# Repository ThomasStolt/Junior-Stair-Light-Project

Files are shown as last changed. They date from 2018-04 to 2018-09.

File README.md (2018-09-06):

# Junior-Stair-Light-Project

This is a smaller/easier/cheaper version of my NeoPixel Stair Light Project. The basic idea is to use a bunch of cheap 12V LEDs stripes attached to your indoor stairs, two IR sensors and an Arduino Nano and animate those LED stripes if a person is walking up or down the stairs.

I created this for a friend of mine. He went out on the internet and bought sets of LED stripes (originally thought for cars, 12V) and mounted them under the stairs. I then went ahead and created this little project around it, giving it some more fun.

For several reasons, all grounds of the LED stripes were connected together and all the positive leads were routed to the circuit for switching/PWM. Because of that, I had to use that dual-transistor circuit, which I found on the internet, to be able to switch the positive lines.
It is actually easier to switch the negative lines, that just requires one transistor/MOSFET, so if you do this and you have a choice, you should probably go with that approach.

Nothing more to add really, just read the circuit under schematics/kicad (there is a PDF) and you should be good.

# Needed Materials:

- Power supply, 12V DC, 2A should be enough (I found a 3A in my mess)
- 1 x Arduino Nano
- 2 x 10k resistors (optional, pull up for PIR sensors, I did not need to use them)
- 1 x 5V regulator (L4940V5)
- 2 x 100uF electrolytic capacitor
- 1 x 100nF ceramic capacitor
- a project box to house the electronics

Then _per step_ you need:
- 1 x LED stripe (12V, for cars)
- 2 x 1kOhm resistor
- 1 x 10kOhm resistor
- 1 x BC337 (or similar) NPN Transistor
- 1 x BC327 (or similar) PNP Transistor

Additionally you need a prototype board (or the PCB, see below) for soldering components, some wires for connecting the components, tools (soldering iron, solder, cutter, clippers, a Dremel helps to cut the copper on the board) and some time and patience.

# Printed Circuit Board
I have created a first "Release Candidate" (RC) of a printed circuit board for this project. I added the maximum number of channels (steps) that an Arduino Nano can have, which is number of Digital outputs + number of Analog outputs - 2 analog outputs (for the IR sensors), which should end up at 18.

So, 18 is the maximum number of steps your stairs can have using this single Arduino Nano module. If you have less stairs, just populate the board with the appropriate number of parts for the channels. If you have more stairs - well, you are on your own.

To order the PCB you'll need to send/upload the Gerber files to a PCB manufacturer of your choice. You can find the Gerber files here: [Gerbes](schematics/kicad/GERBERS), just use the ZIP archive. The board is 9cm x 9cm, currently you get special offers for 2$ for 10 pieces - ridicolous!

As of today (Sep 2018), I have not yet ordered a PCB, so I cannot say whether this PCB is really working, it might still be full of bugs! Try at your own risk!

# Steps:
1. buy all the material
2. create the board (see pictures), start with one channel first
3. test that first channel
4. create all the channels
5. stick it to your stairs

# Pictures

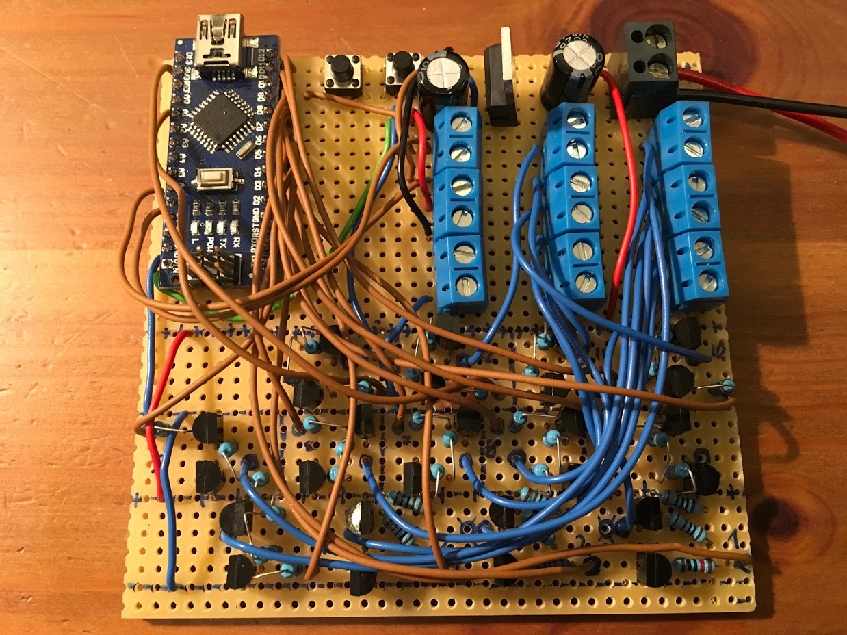
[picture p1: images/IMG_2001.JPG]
finished board top

This is the finished board, top view.

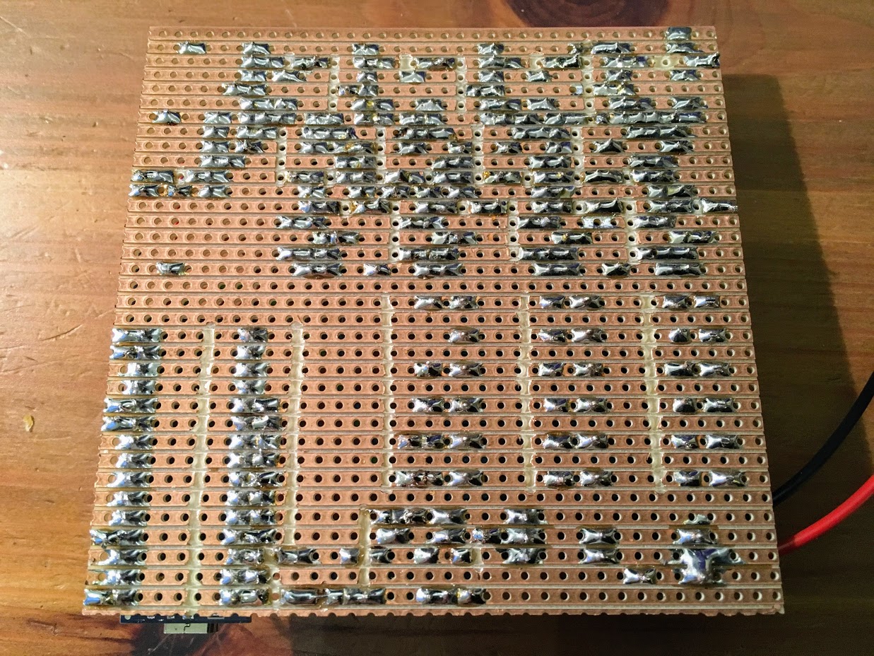
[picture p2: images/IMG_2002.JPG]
finished board bottom

This is the finished board on a prototype PCB, bottom view.

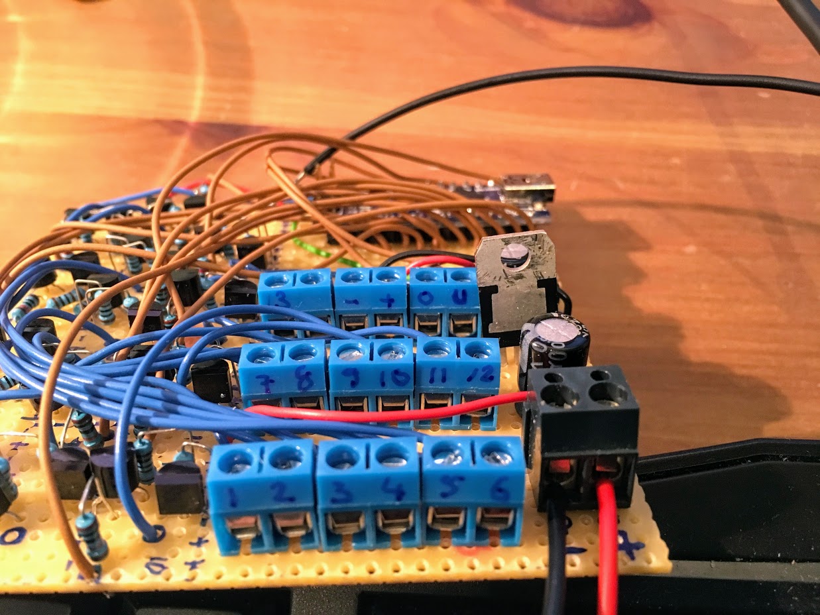
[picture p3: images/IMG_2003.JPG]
connectors view

These are the connectors for the LED strips, power and IR sensors

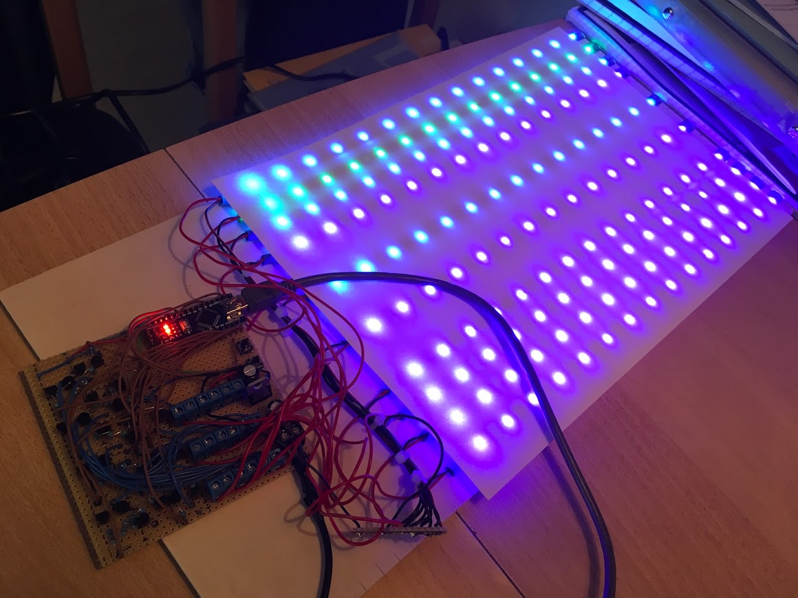
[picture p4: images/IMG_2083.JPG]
test setup

The test setup for finishing the code.
I did not have enough left over stripes, hence there are some missing here, but that is sufficient.

This can probably be done on one weekend if you are somewhat experienced.

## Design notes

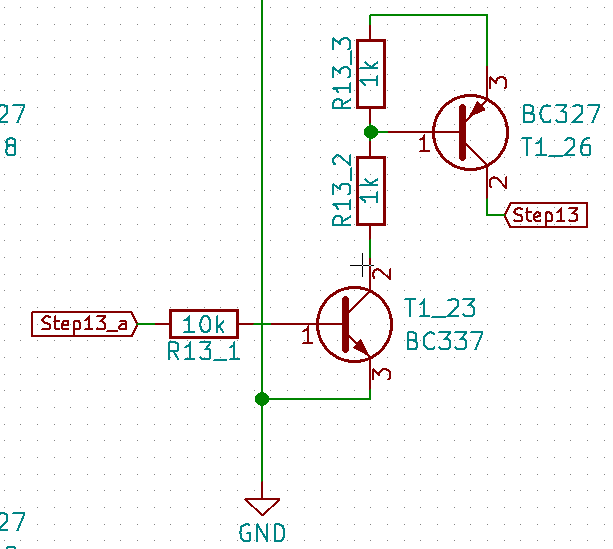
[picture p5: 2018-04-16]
images/Bildschirmfoto vom 2018-04-16 23-10-50.png

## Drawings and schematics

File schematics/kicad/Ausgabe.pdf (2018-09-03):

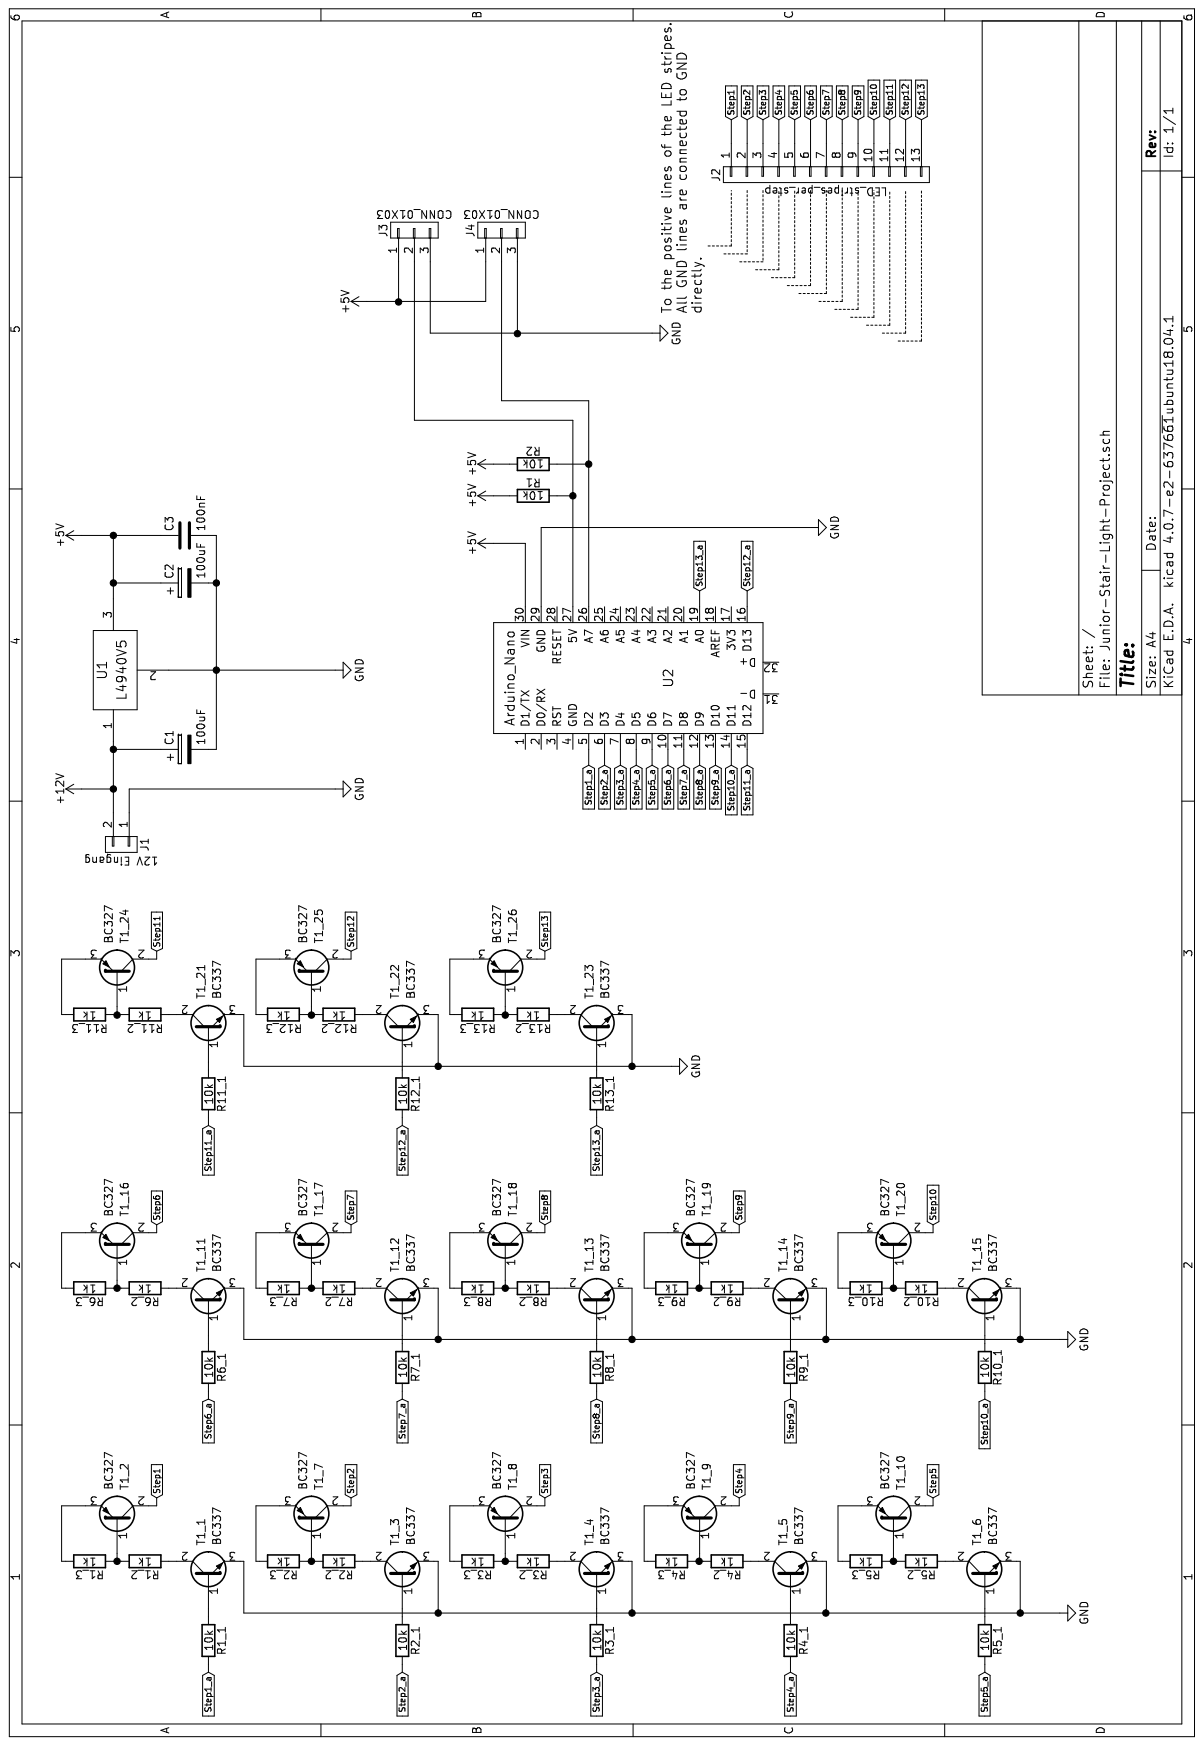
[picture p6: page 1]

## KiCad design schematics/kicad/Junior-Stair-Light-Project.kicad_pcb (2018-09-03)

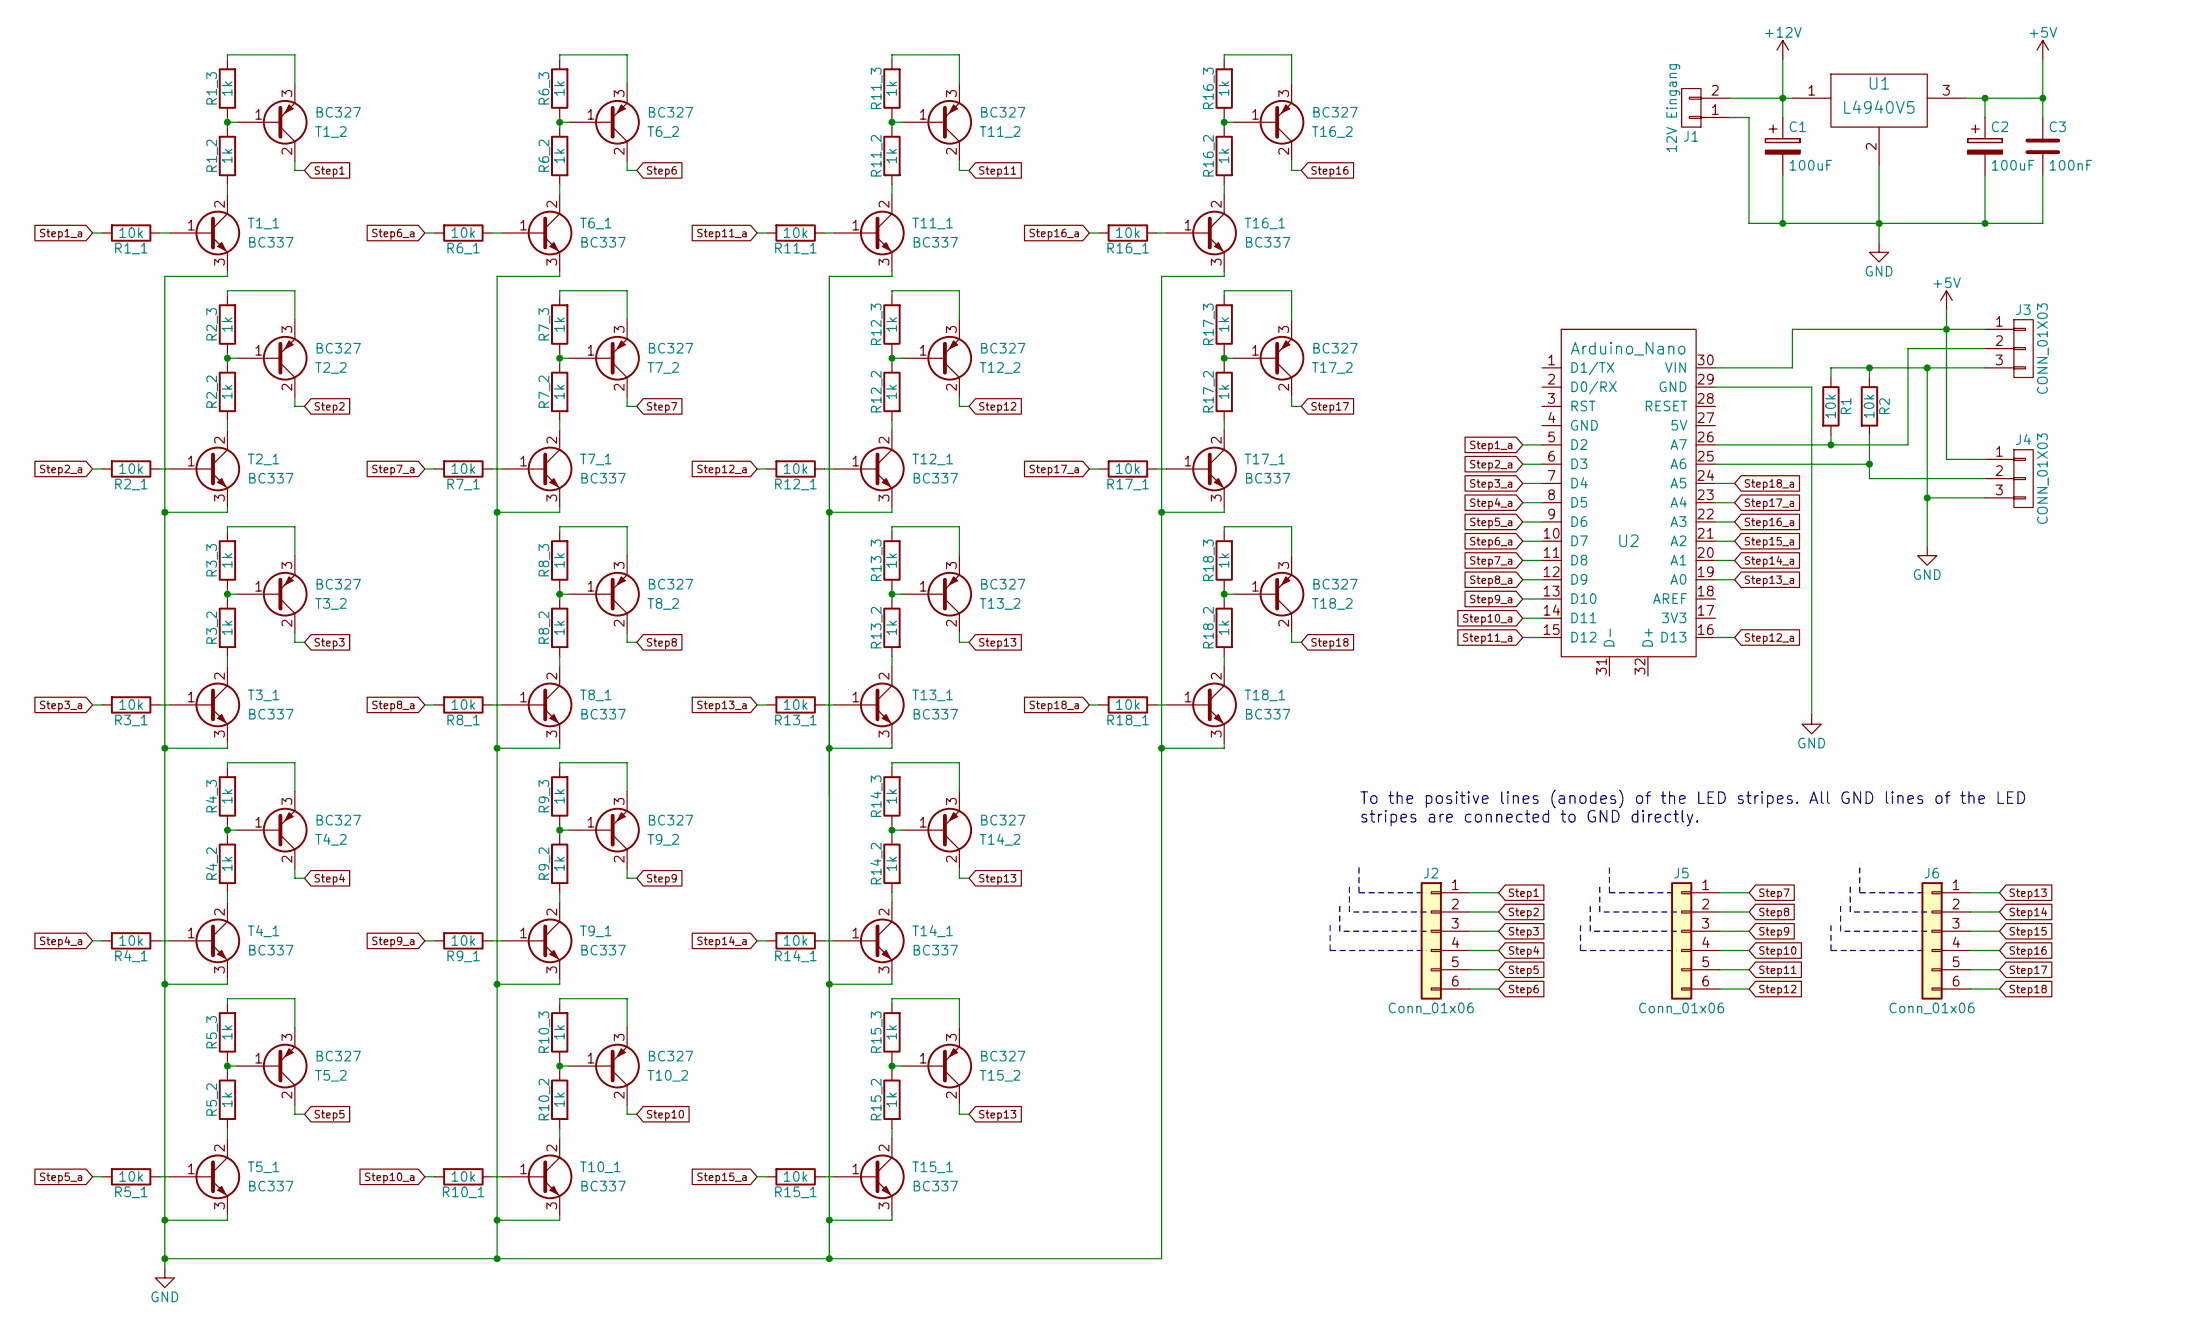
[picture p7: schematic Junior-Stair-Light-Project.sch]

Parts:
C1, C2: 100uF; CP_Radial_D7.5mm_P2.50mm
C3: 100nF; C_Disc_D3.8mm_W2.6mm_P2.50mm
J1: 12V Eingang; JST_XH_B02B-XH-A_02x2.50mm_Straight
J2, J5, J6: Conn_01x06; JST_XH_B06B-XH-A_06x2.50mm_Straight
J3, J4: CONN_01X03; JST_XH_B03B-XH-A_03x2.50mm_Straight
R1, R1_1, R2, R2_1, R3_1, R4_1, R5_1, R6_1, R7_1, R8_1, R9_1, R10_1, R11_1, R12_1, R13_1, R14_1, R15_1, R16_1, R17_1, R18_1: 10k; R_Axial_DIN0207_L6.3mm_D2.5mm_P7.62mm_Horizontal
R1_2, R1_3, R2_2, R2_3, R3_2, R3_3, R4_2, R4_3, R5_2, R5_3, R6_2, R6_3, R7_2, R7_3, R8_2, R8_3, R9_2, R9_3, R10_2, R10_3, R11_2, R11_3, R12_2, R12_3, R13_2, R13_3, R14_2, R14_3, R15_2, R15_3, R16_2, R16_3, R17_2, R17_3, R18_2, R18_3: 1k; R_Axial_DIN0207_L6.3mm_D2.5mm_P7.62mm_Horizontal
T1_1, T2_1, T3_1, T4_1, T5_1, T6_1, T7_1, T8_1, T9_1, T10_1, T11_1, T12_1, T13_1, T14_1, T15_1, T16_1, T17_1, T18_1: BC337; TO-92_Inline_Narrow_Oval
T1_2, T2_2, T3_2, T4_2, T5_2, T6_2, T7_2, T8_2, T9_2, T10_2, T11_2, T12_2, T13_2, T14_2, T15_2, T16_2, T17_2, T18_2: BC327; TO-92_Inline_Narrow_Oval
U1: L4940V5; TO-220_Vertical
U2: Arduino_Nano

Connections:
+5V: C2.1, C3.1, J3.1, J4.1, U1.3, U2.30 (VIN)
+12V: C1.1, J1.2, U1.1
GND: C1.2, C2.2, C3.2, J1.1, J3.3, J4.3, R1.1, R2.1, T1_1.3 (E), T2_1.3 (E), T3_1.3 (E), T4_1.3 (E), T5_1.3 (E), T6_1.3 (E), T7_1.3 (E), T8_1.3 (E), T9_1.3 (E), T10_1.3 (E), T11_1.3 (E), T12_1.3 (E), T13_1.3 (E), T14_1.3 (E), T15_1.3 (E), T16_1.3 (E), T17_1.3 (E), T18_1.3 (E), U1.2, U2.29 (GND)
unnamed: J3.2, R1.2, U2.26 (A7)
unnamed: J4.2, R2.2, U2.25 (A6)
unnamed: R1_1.1, T1_1.1 (B)
unnamed: R1_2.1, R1_3.1, T1_2.1 (B)
unnamed: R1_2.2, T1_1.2 (C)
unnamed: R1_3.2, T1_2.3 (E)
unnamed: R2_1.1, T2_1.1 (B)
unnamed: R2_2.1, R2_3.1, T2_2.1 (B)
unnamed: R2_2.2, T2_1.2 (C)
unnamed: R2_3.2, T2_2.3 (E)
unnamed: R3_1.1, T3_1.1 (B)
unnamed: R3_2.1, R3_3.1, T3_2.1 (B)
unnamed: R3_2.2, T3_1.2 (C)
unnamed: R3_3.2, T3_2.3 (E)
unnamed: R4_1.1, T4_1.1 (B)
unnamed: R4_2.1, R4_3.1, T4_2.1 (B)
unnamed: R4_2.2, T4_1.2 (C)
unnamed: R4_3.2, T4_2.3 (E)
unnamed: R5_1.1, T5_1.1 (B)
unnamed: R5_2.1, R5_3.1, T5_2.1 (B)
unnamed: R5_2.2, T5_1.2 (C)
unnamed: R5_3.2, T5_2.3 (E)
unnamed: R6_1.1, T6_1.1 (B)
unnamed: R6_2.1, R6_3.1, T6_2.1 (B)
unnamed: R6_2.2, T6_1.2 (C)
unnamed: R6_3.2, T6_2.3 (E)
unnamed: R7_1.1, T7_1.1 (B)
unnamed: R7_2.1, R7_3.1, T7_2.1 (B)
unnamed: R7_2.2, T7_1.2 (C)
unnamed: R7_3.2, T7_2.3 (E)
unnamed: R8_1.1, T8_1.1 (B)
unnamed: R8_2.1, R8_3.1, T8_2.1 (B)
unnamed: R8_2.2, T8_1.2 (C)
unnamed: R8_3.2, T8_2.3 (E)
unnamed: R9_1.1, T9_1.1 (B)
unnamed: R9_2.1, R9_3.1, T9_2.1 (B)
unnamed: R9_2.2, T9_1.2 (C)
unnamed: R9_3.2, T9_2.3 (E)
unnamed: R10_1.1, T10_1.1 (B)
unnamed: R10_2.1, R10_3.1, T10_2.1 (B)
unnamed: R10_2.2, T10_1.2 (C)
unnamed: R10_3.2, T10_2.3 (E)
unnamed: R11_1.1, T11_1.1 (B)
unnamed: R11_2.1, R11_3.1, T11_2.1 (B)
unnamed: R11_2.2, T11_1.2 (C)
unnamed: R11_3.2, T11_2.3 (E)
unnamed: R12_1.1, T12_1.1 (B)
unnamed: R12_2.1, R12_3.1, T12_2.1 (B)
unnamed: R12_2.2, T12_1.2 (C)
unnamed: R12_3.2, T12_2.3 (E)
unnamed: R13_1.1, T13_1.1 (B)
unnamed: R13_2.1, R13_3.1, T13_2.1 (B)
unnamed: R13_2.2, T13_1.2 (C)
unnamed: R13_3.2, T13_2.3 (E)
unnamed: R14_1.1, T14_1.1 (B)
unnamed: R14_2.1, R14_3.1, T14_2.1 (B)
unnamed: R14_2.2, T14_1.2 (C)
unnamed: R14_3.2, T14_2.3 (E)
unnamed: R15_1.1, T15_1.1 (B)
unnamed: R15_2.1, R15_3.1, T15_2.1 (B)
unnamed: R15_2.2, T15_1.2 (C)
unnamed: R15_3.2, T15_2.3 (E)
unnamed: R16_1.1, T16_1.1 (B)
unnamed: R16_2.1, R16_3.1, T16_2.1 (B)
unnamed: R16_2.2, T16_1.2 (C)
unnamed: R16_3.2, T16_2.3 (E)
unnamed: R17_1.1, T17_1.1 (B)
unnamed: R17_2.1, R17_3.1, T17_2.1 (B)
unnamed: R17_2.2, T17_1.2 (C)
unnamed: R17_3.2, T17_2.3 (E)
unnamed: R18_1.1, T18_1.1 (B)
unnamed: R18_2.1, R18_3.1, T18_2.1 (B)
unnamed: R18_2.2, T18_1.2 (C)
unnamed: R18_3.2, T18_2.3 (E)
Step1: J2.1, T1_2.2 (C)
Step1_a: R1_1.2, U2.5 (D2)
Step2: J2.2, T2_2.2 (C)
Step2_a: R2_1.2, U2.6 (D3)
Step3: J2.3, T3_2.2 (C)
Step3_a: R3_1.2, U2.7 (D4)
Step4: J2.4, T4_2.2 (C)
Step4_a: R4_1.2, U2.8 (D5)
Step5: J2.5, T5_2.2 (C)
Step5_a: R5_1.2, U2.9 (D6)
Step6: J2.6, T6_2.2 (C)
Step6_a: R6_1.2, U2.10 (D7)
Step7: J5.1, T7_2.2 (C)
Step7_a: R7_1.2, U2.11 (D8)
Step8: J5.2, T8_2.2 (C)
Step8_a: R8_1.2, U2.12 (D9)
Step9: J5.3, T9_2.2 (C)
Step9_a: R9_1.2, U2.13 (D10)
Step10: J5.4, T10_2.2 (C)
Step10_a: R10_1.2, U2.14 (D11)
Step11: J5.5, T11_2.2 (C)
Step11_a: R11_1.2, U2.15 (D12)
Step12: J5.6, T12_2.2 (C)
Step12_a: R12_1.2, U2.16 (D13)
Step13: J6.1, T13_2.2 (C), T14_2.2 (C), T15_2.2 (C)
Step13_a: R13_1.2, U2.19 (A0)
Step14: J6.2
Step14_a: R14_1.2, U2.20 (A1)
Step15: J6.3
Step15_a: R15_1.2, U2.21 (A2)
Step16: J6.4, T16_2.2 (C)
Step16_a: R16_1.2, U2.22 (A3)
Step17: J6.5, T17_2.2 (C)
Step17_a: R17_1.2, U2.23 (A4)
Step18: J6.6, T18_2.2 (C)
Step18_a: R18_1.2, U2.24 (A5)

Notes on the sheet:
To the positive lines (anodes) of the LED stripes. All GND lines of the LED stripes are connected to GND directly.

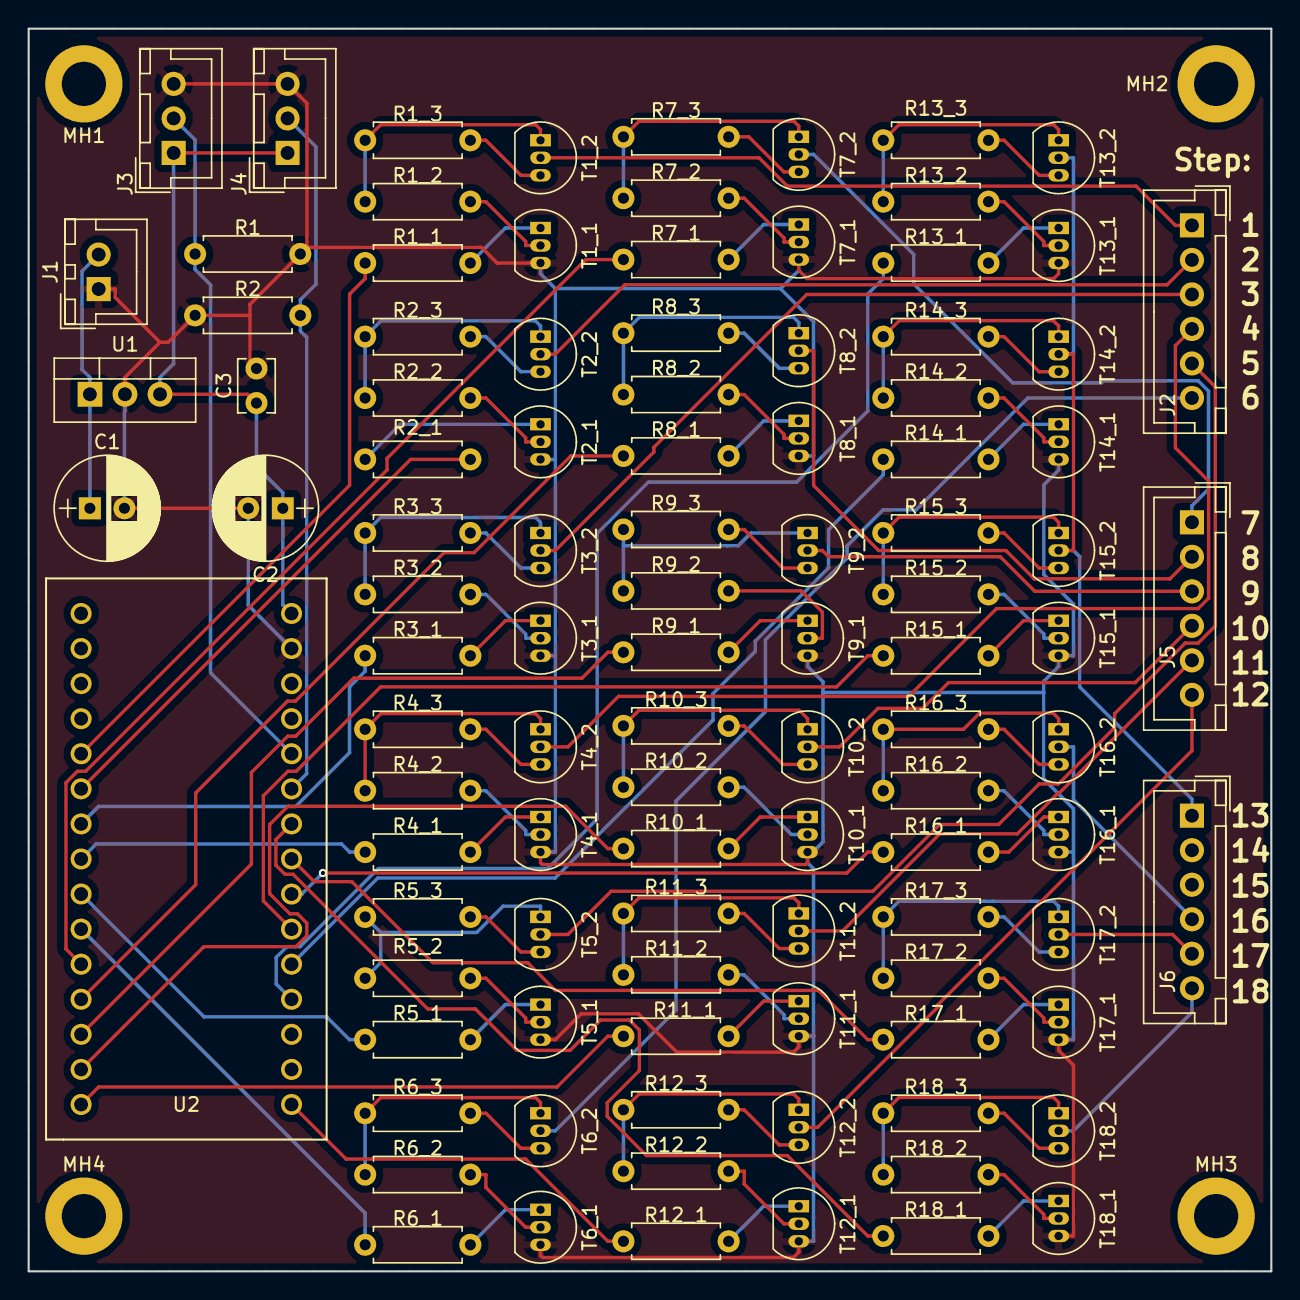
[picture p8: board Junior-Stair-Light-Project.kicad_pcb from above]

Board: 2 copper layers, 90.0 x 90.0 mm, 107 parts (0 on the bottom side), 111 nets.

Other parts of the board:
MH1: MH1; MountingHole_3.2mm_M3_DIN965_Pad
MH2: MH2; MountingHole_3.2mm_M3_DIN965_Pad
MH3: MH3; MountingHole_3.2mm_M3_DIN965_Pad
MH4: MH4; MountingHole_3.2mm_M3_DIN965_Pad

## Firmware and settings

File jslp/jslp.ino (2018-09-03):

/*
  Junior Stair Light Project
  ==========================
  This is an Arduino Nano based project. The idea is to illuminate
  a flight of stairs with some dirt cheap LED stripes, also adding
  some animation (dimming). All triggered by IR sensors.
  
  Project cost: 50€ max!
  
  I was equiping my own stairs with some RGBWW  NeoPixels, while a
  friend  of  mine  was  inspired  and  went  out  shopping on the
  internet  on a shoestring. He bought LED stripes from an obscure
  company (XINBAN). 9€ for 8 strips,  30cm  and  15LEDs each, they
  need 12V to operate.  While  crappy, I thought I could still add
  some animation and dimming functionality to it.

  I have used the Arduino-SoftPWM, which allows  you  to  use  all
  digital  AND  analog  pins for PWM. This flight of stairs has 13
  steps, but in this  configuration this project can be used up to
  18 steps.
*/

#include <SoftPWM.h>
SOFTPWM_DEFINE_CHANNEL(2, DDRD, PORTD, PORTD2);  //Arduino pin D2
SOFTPWM_DEFINE_CHANNEL(3, DDRD, PORTD, PORTD3);  //Arduino pin D3
SOFTPWM_DEFINE_CHANNEL(4, DDRD, PORTD, PORTD4);  //Arduino pin D4
SOFTPWM_DEFINE_CHANNEL(5, DDRD, PORTD, PORTD5);  //Arduino pin D5
SOFTPWM_DEFINE_CHANNEL(6, DDRD, PORTD, PORTD6);  //Arduino pin D6
SOFTPWM_DEFINE_CHANNEL(7, DDRD, PORTD, PORTD7);  //Arduino pin D7
SOFTPWM_DEFINE_CHANNEL(8, DDRB, PORTB, PORTB0);  //Arduino pin D8
SOFTPWM_DEFINE_CHANNEL(9, DDRB, PORTB, PORTB1);  //Arduino pin D9
SOFTPWM_DEFINE_CHANNEL(10, DDRB, PORTB, PORTB2);  //Arduino pin D10
SOFTPWM_DEFINE_CHANNEL(11, DDRB, PORTB, PORTB3);  //Arduino pin D11
SOFTPWM_DEFINE_CHANNEL(12, DDRB, PORTB, PORTB4);  //Arduino pin D12
SOFTPWM_DEFINE_CHANNEL(13, DDRB, PORTB, PORTB5);  //Arduino pin D13
SOFTPWM_DEFINE_CHANNEL(14, DDRC, PORTC, PORTC0);  //Arduino pin A0
SOFTPWM_DEFINE_OBJECT_WITH_PWM_LEVELS(20, 100);
SOFTPWM_DEFINE_EXTERN_OBJECT_WITH_PWM_LEVELS(20, 100);

void setup() {
  Serial.begin(19200);
  // begin with 60hz pwm frequency
  Palatis::SoftPWM.begin(60);
  // print interrupt load for diagnostic purposes
  Palatis::SoftPWM.printInterruptLoad();
}

static volatile uint8_t v = 0;
int analog_threshold = 100;
int animation_duration = 30000;
int pra=analogRead(7);
int prb=analogRead(6);
int time_s, time_c;

void loop() {
    delay(100);
    
     // while(true){
     pra=analogRead(7);
     prb=analogRead(6);
     // Serial.println("-----------------");
     Serial.println(pra);
     Serial.println(prb);
     //  delay(1000);
    // }

    
    // Direction 1 on
    if ( pra > analog_threshold ) {
      for (uint8_t i = 2; i < 15; ++i) {
        Serial.print(micros());
        Serial.print(" loop(): ");
        Serial.println(i);
        unsigned long const WAIT = 600000 / Palatis::SoftPWM.PWMlevels() / 2;
        unsigned long nextMicros = 0;
        for (int v = 0; v < Palatis::SoftPWM.PWMlevels() - 1; ++v) {
          while (micros() < nextMicros);
          nextMicros = micros() + WAIT;
          Palatis::SoftPWM.set(i, v);
        }
      }
      
      // set a start timer, so we know how much time has passed
      time_s = millis();
      while(true) {
        delay(100);
        Serial.print(".");
        // read the "other" PRI
        prb=analogRead(6);
        // this exits the while loop when we detect the other PRI triggered
        if ( prb > analog_threshold ) {
          break;
        }
        // this exists the while loop when animation_duration seconds have passed
        time_c = millis();
        if ((time_c - time_s) > animation_duration) {
          break;
        }
      }
      
      // Direction 1 off
      for (uint8_t i = 2; i < 15; ++i) {
        Serial.print(micros());
        Serial.print(" loop(): ");
        Serial.println(i);
        unsigned long const WAIT = 600000 / Palatis::SoftPWM.PWMlevels() / 2;
        unsigned long nextMicros = 0;
        for (int v = Palatis::SoftPWM.PWMlevels() - 1; v >= 0; --v) {
          while (micros() < nextMicros);
          nextMicros = micros() + WAIT;
          Palatis::SoftPWM.set(i, v);
        }
      }
      delay(1000);
    }
    
    pra=analogRead(7);
    prb=analogRead(6);
    // Direction 2 on
    if (prb > analog_threshold) {
      for (uint8_t i = 14; i > 1; --i) {
        Serial.print(micros());
        Serial.print(" loop(): ");
        Serial.println(i);
        unsigned long const WAIT = 600000 / Palatis::SoftPWM.PWMlevels() / 2;
        unsigned long nextMicros = 0;
        for (int v = 0; v < Palatis::SoftPWM.PWMlevels() - 1; ++v) {
          while (micros() < nextMicros);
          nextMicros = micros() + WAIT;
          Palatis::SoftPWM.set(i, v);
        }
      }

      // set a start timer, so we know how much time has passed
      time_s = millis();
      while(true) {
        delay(100);
        Serial.print(".");
        // read the "other" PRI
        prb=analogRead(7);
        // this exits the while loop when we detect the other PRI triggered
        if ( prb > analog_threshold ) {
          break;
        }
        // this exists the while loop when animation_duration seconds have passed
        time_c = millis();
        if ((time_c - time_s) > animation_duration) {
          break;
        }
      }
      
      // Direction 2 off
      for (uint8_t i = 14; i > 1; --i) {
        Serial.print(micros());
        Serial.print(" loop(): ");
        Serial.println(i);
        unsigned long const WAIT = 600000 / Palatis::SoftPWM.PWMlevels() / 2;
        unsigned long nextMicros = 0;
        for (int v = Palatis::SoftPWM.PWMlevels() - 1; v >= 0; --v) {
          while (micros() < nextMicros);
          nextMicros = micros() + WAIT;
         Palatis::SoftPWM.set(i, v);
        }
      }
      delay(1000);
    }    
  }

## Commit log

2018-04-16 changed 12v switching
    [Junior-Stair-Light-Project.kicad_pcb, Junior-Stair-Light-Project.sch, Untitled Sketch.fzz]
2018-04-16 First edition of PCB done
    [Junior-Stair-Light-Project.dsn, Junior-Stair-Light-Project.sch]
2018-04-29 new stuff
    [Junior-Stair-Light-Project.dsn]
2018-08-31 Some changes
    [Junior-Stair-Light-Project.sch]
2018-08-31 First RC of code is ready
    [Junior-Stair-Light-Project.sch]
2018-09-03 Added max channels (19) and finished first RC of PCB layout
    [Junior-Stair-Light-Project.dsn, Junior-Stair-Light-Project.kicad_pcb, Junior-Stair-Light-Project.sch]
2018-09-03 Created gerber files
    [Junior-Stair-Light-Project-B.Cu.gbr, Junior-Stair-Light-Project-B.Mask.gbr, Junior-Stair-Light-Project-B.Paste.gbr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]
2018-09-03 Corrected connectivity, there was a bug
    [Junior-Stair-Light-Project.kicad_pcb, Junior-Stair-Light-Project.sch]
2018-09-03 Updates, updates, updates
    [Junior-Stair-Light-Project-B.Cu.gbr, Junior-Stair-Light-Project-B.Mask.gbr, Junior-Stair-Light-Project-B.Paste.gbr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]
2018-09-03 some cleanup
    [Untitled Sketch.fzz]
